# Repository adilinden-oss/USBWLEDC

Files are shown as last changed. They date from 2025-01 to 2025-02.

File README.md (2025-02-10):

# USBWLEDC
USB Sound Reactive WLED Controller



## Why This Fork?

This is my fork of the [NandXor96/USBWLEDC](https://github.com/NandXor96/USBWLEDC) WLED Controller.  There is a [Reddit post](https://www.reddit.com/r/WLED/comments/1c1dhp0/comment/kz3xn8g/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) explaining how to order the (mostly) assembled board from JLCPCB.  Unfortunately, when I went to order it turned out that neither the **GSA4737** nor the (pin compatible?) **SPM1423** were available. Checking parts sources, they appear to be obsolete at this point.  I redesigned the board to support the **ICS-43434** instead, which is a current stocked part (albeit more expensive!).

The included production files were created with KiCAD v8.0.7 and exported using the [KiCAD JLCPCB Tools Plugin](https://github.com/Bouni/kicad-jlcpcb-tools).

## Features

- USB-C for flashing and power (max. 3A)
- Small size (30mm x 35mm)
- Cheap components
- GSA4737 MEMS Microphone (similar to SPM1423)
- Solder Pads instead of Screw Terminal Blocks
- Files for panelized version (4x4)
- Files for 3D printed case
- Front side can be populated by JLCPCB

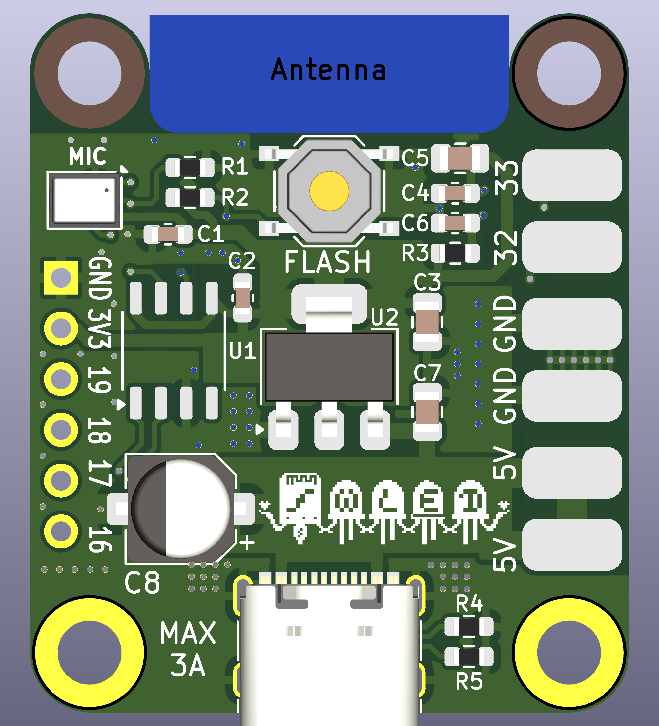
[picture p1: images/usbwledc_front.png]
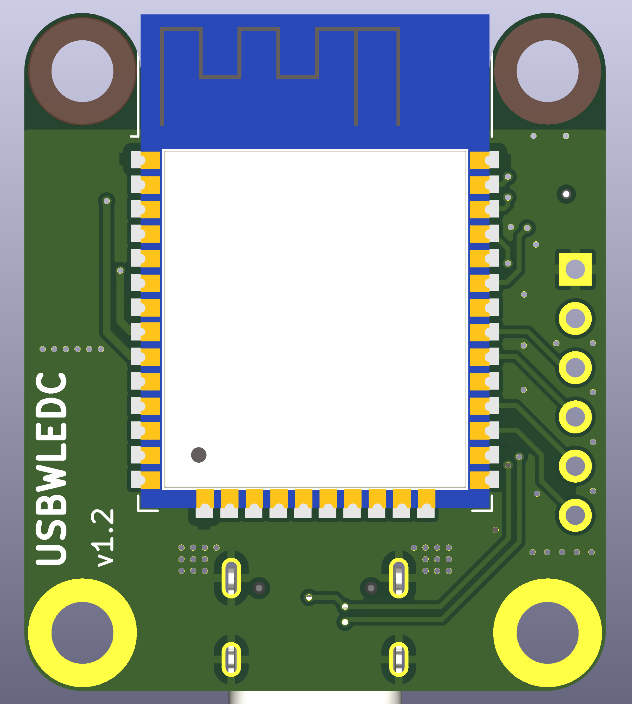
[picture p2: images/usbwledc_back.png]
 

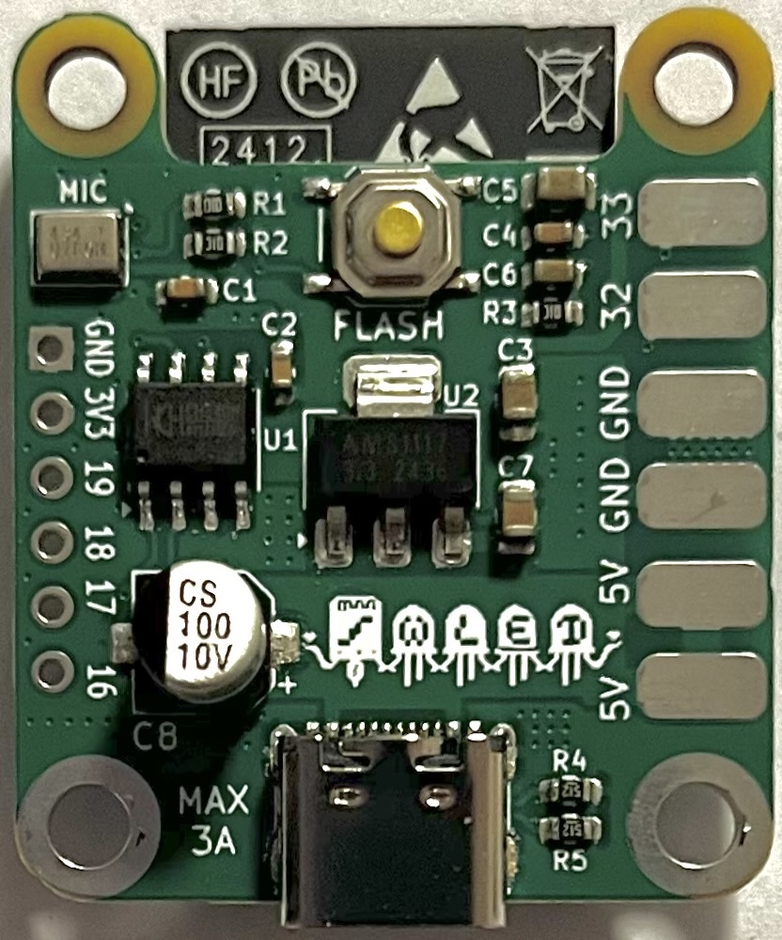
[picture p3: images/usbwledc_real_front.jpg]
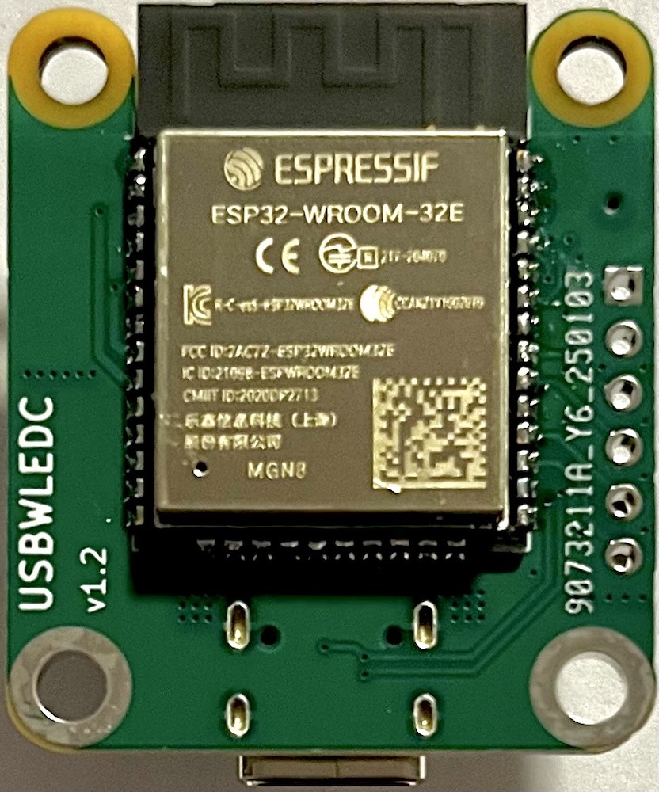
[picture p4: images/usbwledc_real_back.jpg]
 

## In Action

Here are two brief video clips of WLED with audio reactive enabled on this board.

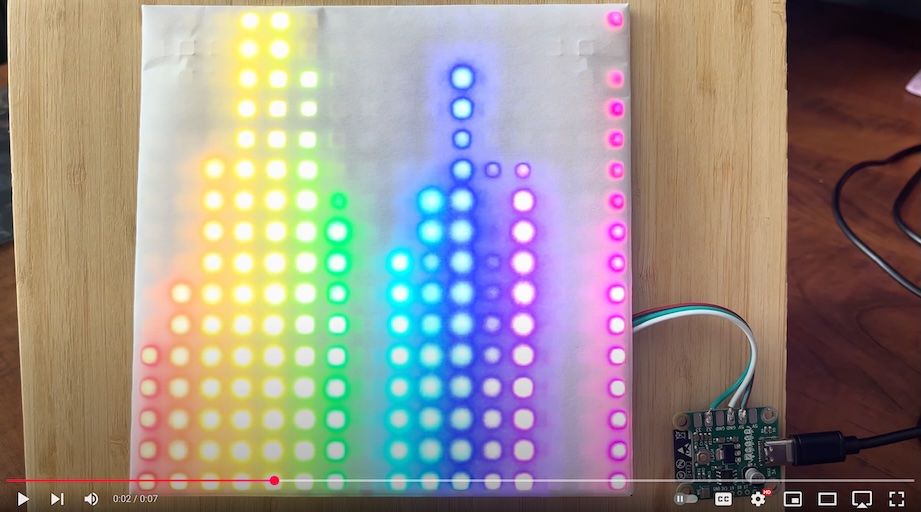
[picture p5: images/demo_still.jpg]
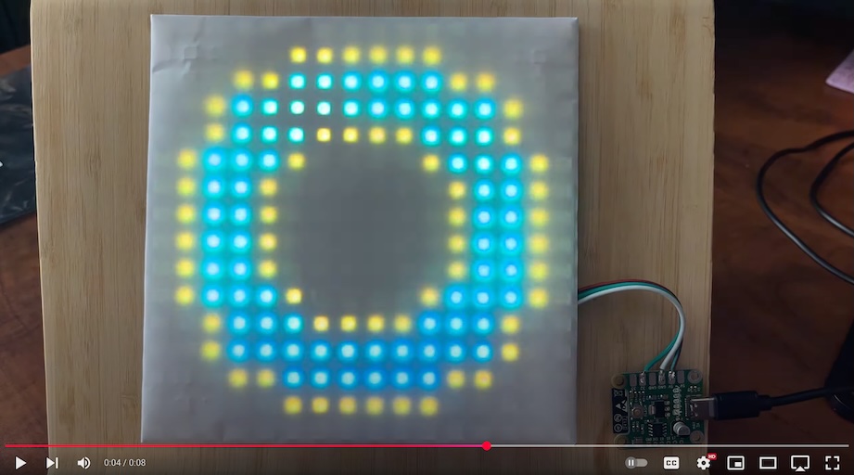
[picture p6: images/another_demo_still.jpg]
[](https://youtu.be/NIZeim1se8Q) [](https://youtu.be/1qbfc3PyaYY)

## Case



## Entering Flash Mode

To enter the Flash mode of the USBWLEDC, simply hold down the button as you connect the USB cable to a computer.

## WLED Config

| Name | Value |
|---|---|
| LED Output 1: GPIO | 32 |
| LED Output 2: GPIO | 33 |
| Button 0: GPIO | 0 |
| Digitalmic: Type | Generic I2S |
| Digitalmic: Pin I2S SD  | GPIO 22 |
| Digitalmic: Pin I2S WS  | GPIO 23 |
| Digitalmic: Pin I2S SCK | GPIO 21 |

## BOM

|Designators |Footprint |Quantity|Value |LCSC Part #|
|---|---|---|---|---|
|C1*, C2, C4|Capacitor_SMD:C_0603_1608Metric |3 |100nF |C14663  |
|C3, C5, C7 |Capacitor_SMD:C_0805_2012Metric |3 |10uF |C15850  |
|C6 |Capacitor_SMD:C_0603_1608Metric |1 |1uF |C15849  |
|C8 |Capacitor_SMD:CP_Elec_5x5.4 |1 |100uF |C96182  |
|J10 |Connector_USB:USB_C_Receptacle_G-Switch_GT-USB-7010ASV |1 |USB-C Receptacle |C2988369|
|MK1* |InvenSense_ICS-43434-6_3.5x2.65mm |1 |ICS-43434 MEMS Mic |C2988369|
|R1* |Resistor_SMD:R_0603_1608Metric |1 |100k |C25803  |
|R2, R3 |Resistor_SMD:R_0603_1608Metric |2 |10k |C25804  |
|R4, R5 |Resistor_SMD:R_0603_1608Metric |2 |5.1k |C23186  |
|SW1 |Button_Switch_SMD:SW_Push_1P1T_XKB_TS-1187A |1 |Push Button Flash |C318884 |
|U1 |Package_SO:SOP-8_3.9x4.9mm_P1.27mm |1 |CH340N |C2977777|
|U2 |Package_TO_SOT_SMD:SOT-223-3_TabPin2 |1 |AMS1117-3.3 |C6186 |
|U3** |RF_Module:ESP32-WROOM-32 |1 |ESP32-WROOM-32 |C701341 |

\* You can build it without the microphone. Then you don't need R1, C1 and MK1.

\*\* The ESP32-WROOM Module can be purchased at a lower cost on AliExpress.

## Assembly

When ordering from JLCPCB, you have the option to get the front side of the board pre-populated - A service I strongly endorse. Subsequently, you'll only need to solder the ESP32-WROOM module onto the reverse side. With sufficient flux, this task can be accomplished with relative ease.

For those looking to populate the whole board, I suggest using a hot plate or a reflow oven for the front side.

    Be careful to keep Isopropyl Alcohol away from the hole of the microphone when cleaning the board!

## Disclaimer

The circuit board provided on this GitHub repository is offered "as is," without any warranties or guarantees of any kind. By accessing and utilizing this circuit board, you acknowledge and agree that you do so at your own risk.

The creator and contributor of this repository, shall not be held responsible or liable for any damages, losses, or injuries that may occur as a result of building and / or using this circuit board. This includes but is not limited to any direct, indirect, consequential, or incidental damages.

Electricity is dangerous. Only attempt this project if you know what you're doing.

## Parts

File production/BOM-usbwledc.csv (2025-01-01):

Comment | Designator | Footprint | LCSC | Quantity
100nF | C1,C2,C4 | C_0603_1608Metric | C14663 | 3
1uF | C6 | C_0603_1608Metric | C15849 | 1
10uF | C3,C5,C7 | C_0805_2012Metric | C15850 | 3
5.1k | R4,R5 | R_0603_1608Metric | C23186 | 2
100k | R1 | R_0603_1608Metric | C25803 | 1
10k | R2,R3 | R_0603_1608Metric | C25804 | 2
CH340N | U1 | SOP-8_3.9x4.9mm_P1.27mm | C2977777 | 1
USB_C_Receptacle_USB2.0 | J10 | USB_C_Receptacle_G-Switch_GT-USB-7010ASV | C2988369 | 1
FLASH_SW | SW1 | SW_Push_1P1T_XKB_TS-1187A | C318884 | 1
ICS-43434 | MK1 | InvenSense_ICS-43434-6_3.5x2.65mm | C5656610 | 1
AMS1117-3.3 | U2 | SOT-223-3_TabPin2 | C6186 | 1
ESP32-WROOM-32 | U3 | ESP32-WROOM-32 | C701341 | 1
100uF | C8 | CP_Elec_5x5.4 | C96182 | 1

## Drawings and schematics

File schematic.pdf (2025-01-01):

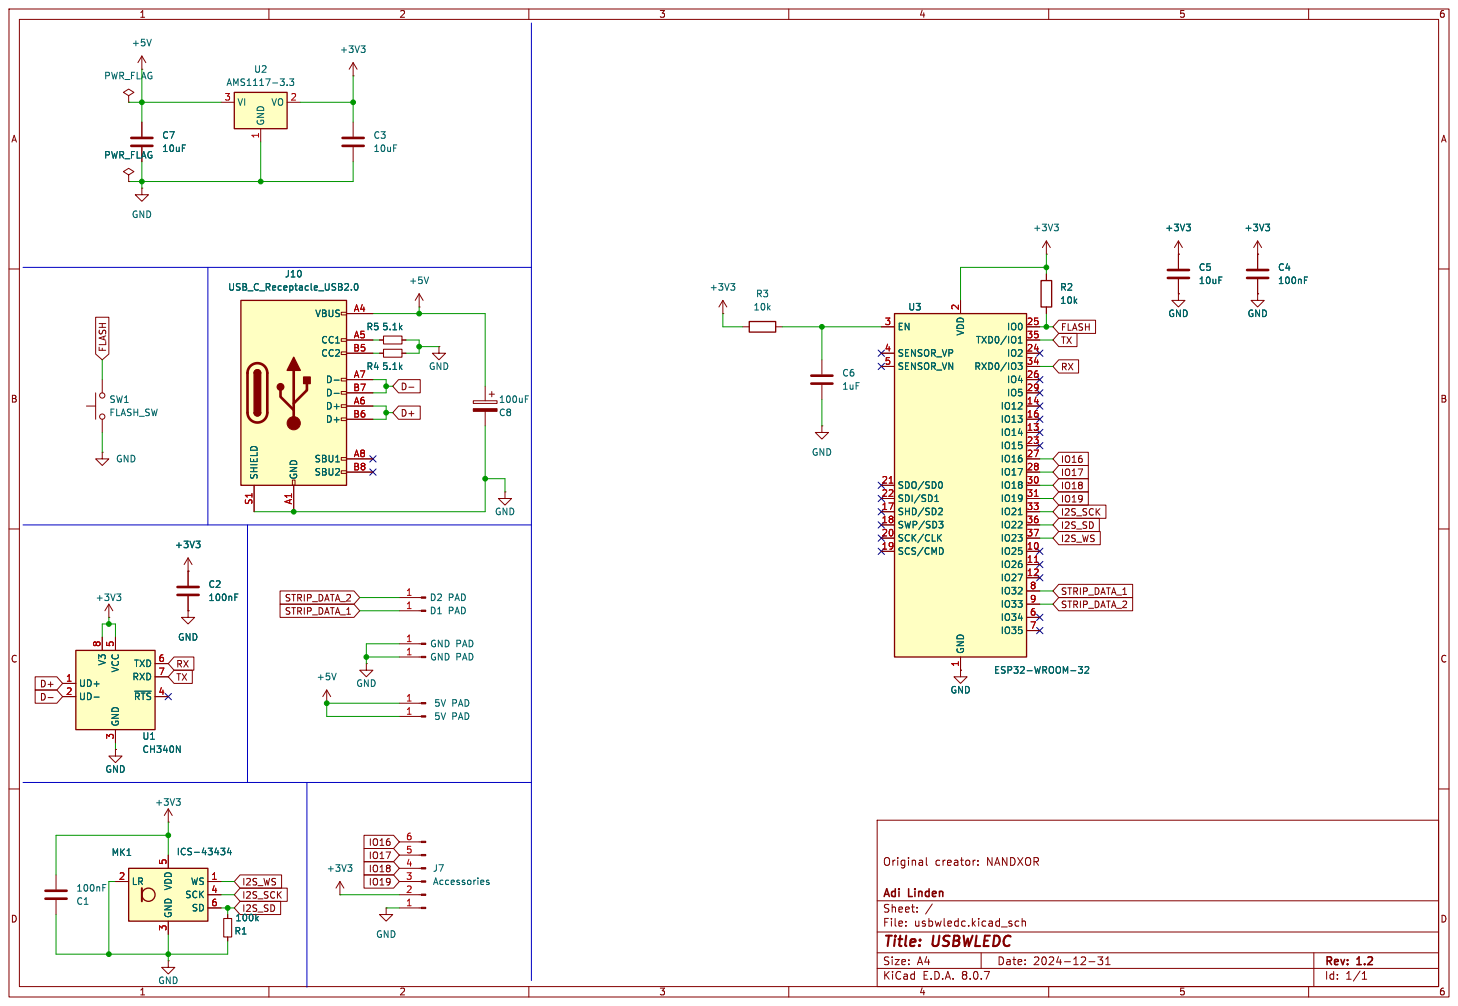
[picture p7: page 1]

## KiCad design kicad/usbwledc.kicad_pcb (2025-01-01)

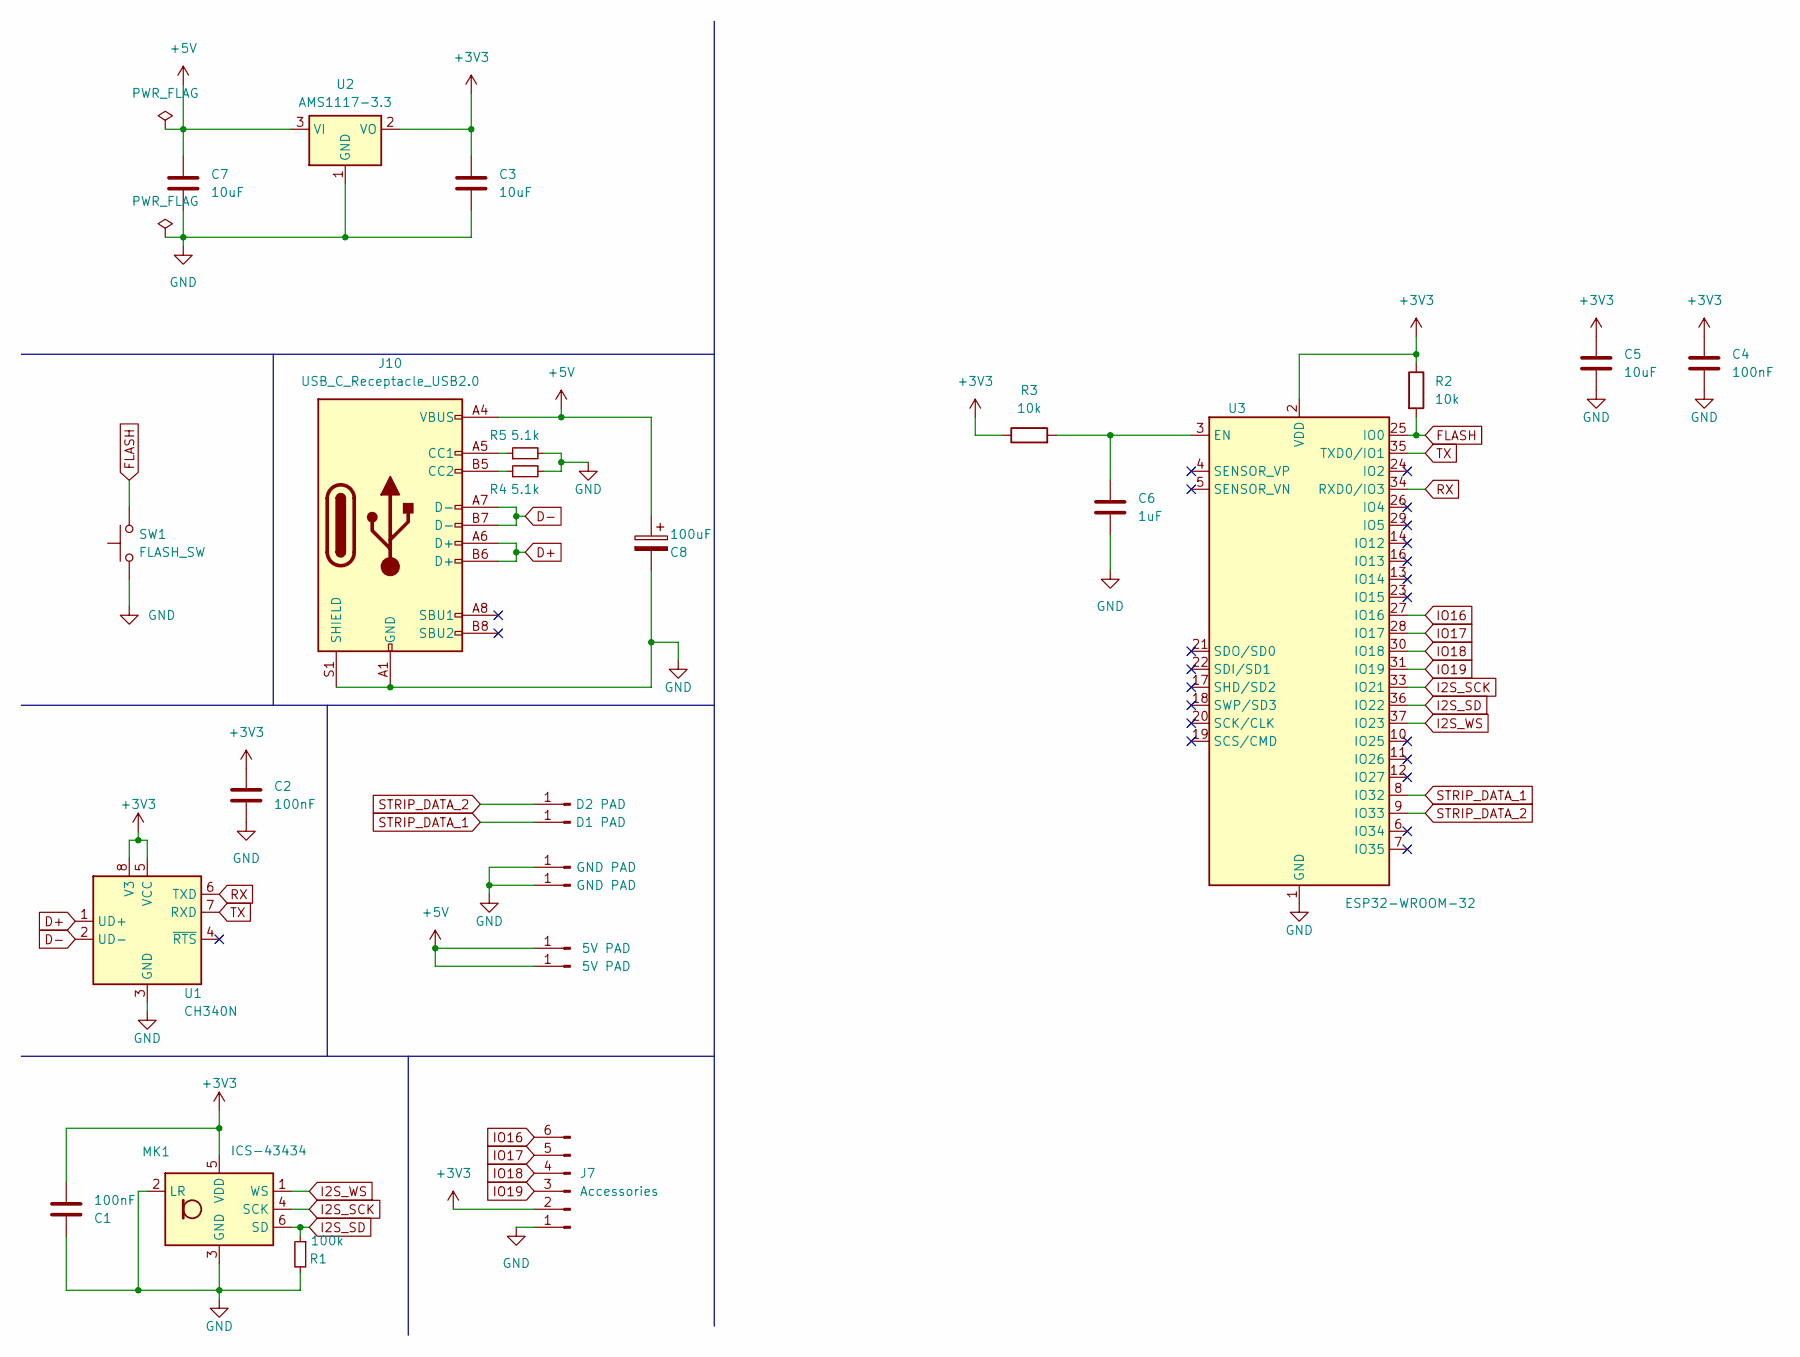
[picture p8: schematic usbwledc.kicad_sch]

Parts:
C1, C2, C4: 100nF; C_0603_1608Metric; MPN C14663; LCSC C14663
C3, C5, C7: 10uF; C_0805_2012Metric; MPN C15850; LCSC C15850
C6: 1uF; C_0603_1608Metric; MPN C15849; LCSC C15849
C8: 100uF; CP_Elec_5x5.4; MPN C131115; LCSC C96182
J1, J4: 5V PAD; SolderWirePad_1x01_SMD_3x6mm
J2: D1 PAD; SolderWirePad_1x01_SMD_3x6mm
J3, J6: GND PAD; SolderWirePad_1x01_SMD_3x6mm
J5: D2 PAD; SolderWirePad_1x01_SMD_3x6mm
J7: Accessories; PinHeader_1x06_P2.54mm_Vertical
J10: USB_C_Receptacle_USB2.0; USB_C_Receptacle_G-Switch_GT-USB-7010ASV; MPN C2988369; LCSC C2988369
MK1: ICS-43434; InvenSense_ICS-43434-6_3.5x2.65mm; LCSC C5656610
R1: 100k; R_0603_1608Metric; MPN C25803; LCSC C25803
R2, R3: 10k; R_0603_1608Metric; MPN C25804; LCSC C25804
R4, R5: 5.1k; R_0603_1608Metric; MPN C23186; LCSC C23186
SW1: FLASH_SW; SW_Push_1P1T_XKB_TS-1187A; MPN C318884; LCSC C318884
U1: CH340N; SOP-8_3.9x4.9mm_P1.27mm; MPN C2977777; LCSC C2977777
U2: AMS1117-3.3; SOT-223-3_TabPin2; MPN C6186; LCSC C6186
U3: ESP32-WROOM-32; MPN C701341; Mouser 356-ESP32WRM32E132PH

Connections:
+3V3: C1.2, C2.2, C3.1, C4.2, C5.1, J7.2, MK1.5 (VDD), R2.1, R3.1, U1.5 (VCC), U1.8 (V3), U2.2 (VO), U3.2 (VDD)
+5V: C7.1, C8.1, J1.1, J4.1, J10.A4 (VBUS), J10.A9 (VBUS), J10.B4 (VBUS), J10.B9 (VBUS), U2.3 (VI)
D+: J10.A6 (D+), J10.B6 (D+), U1.1 (UD+)
D-: J10.A7 (D-), J10.B7 (D-), U1.2 (UD-)
FLASH: R2.2, SW1.2, U3.25 (IO0)
GND: C1.1, C2.1, C3.2, C4.1, C5.2, C6.2, C7.2, C8.2, J3.1, J6.1, J7.1, J10.A1 (GND), J10.A12 (GND), J10.B1 (GND), J10.B12 (GND), J10.S1 (SHIELD), MK1.2 (LR), MK1.3 (GND), R1.2, R4.2, R5.2, SW1.1, U1.3 (GND), U2.1 (GND), U3.1 (GND), U3.15 (GND), U3.38 (GND), U3.39 (GND)
I2S_SCK: MK1.4 (SCK), U3.33 (IO21)
I2S_SD: MK1.6 (SD), R1.1, U3.36 (IO22)
I2S_WS: MK1.1 (WS), U3.37 (IO23)
IO16: J7.6, U3.27 (IO16)
IO17: J7.5, U3.28 (IO17)
IO18: J7.4, U3.30 (IO18)
IO19: J7.3, U3.31 (IO19)
unnamed: J10.A5 (CC1), R5.1
unnamed: J10.B5 (CC2), R4.1
unnamed: C6.1, R3.2, U3.3 (EN)
RX: U1.6 (TXD), U3.34 (RXD0/IO3)
STRIP_DATA_1: J2.1, U3.8 (IO32)
STRIP_DATA_2: J5.1, U3.9 (IO33)
TX: U1.7 (RXD), U3.35 (TXD0/IO1)

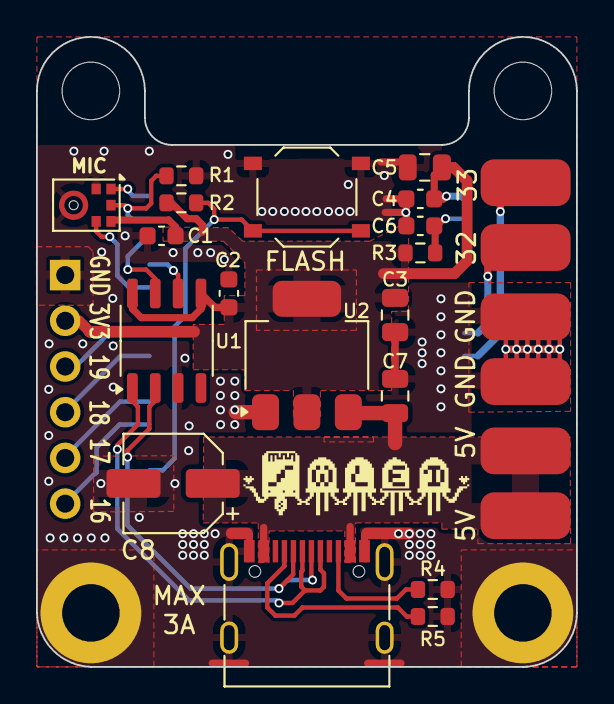
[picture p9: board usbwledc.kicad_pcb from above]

Board: 2 copper layers, 30.0 x 35.0 mm, 30 parts (1 on the bottom side), 20 nets.

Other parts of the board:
H1, H2, H3, H4: MountingHole; MountingHole_3.2mm_M3_DIN965_Pad

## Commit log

2025-01-01 Replaced MEMS mic to a curent available version.
    [BOM-usbwledc.csv, bom.csv, usbwledc.kicad_pcb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]
2025-01-03 Removed files not appropriate
    [panel.kicad_pcb]
